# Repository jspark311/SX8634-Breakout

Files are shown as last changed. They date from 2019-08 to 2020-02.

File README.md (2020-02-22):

# SX8634-Breakout

A breakout board for Semtech's SX8634 capacitive touch sensor.

#### [Hackaday.io Page](https://hackaday.io/project/166853-sx8634-touch-sensor-breakout)

#### [Order from Tindie](https://www.tindie.com/products/17862/)

#### [Arduino driver](https://github.com/jspark311/Arduino-SX8634)

------------------------

### What is in this repository:

**./doc**:  Location for documentation

**./KiCAD**:  Hardware design files

**./lib**:  Third-party libraries

**./main**:  The optional provisioning program

**./downloadDeps.sh**   A script to download dependencies

------------------------

### Building the provisioning program

The provisioning program is intended to be run on an ESP32 devkit-C or comparable. It can be built by doing...

    ./downloadDeps.sh
    make

Then, flash it to the ESP32 board....

    make flash monitor

------------------------

Front | Back
:-------:|:------:
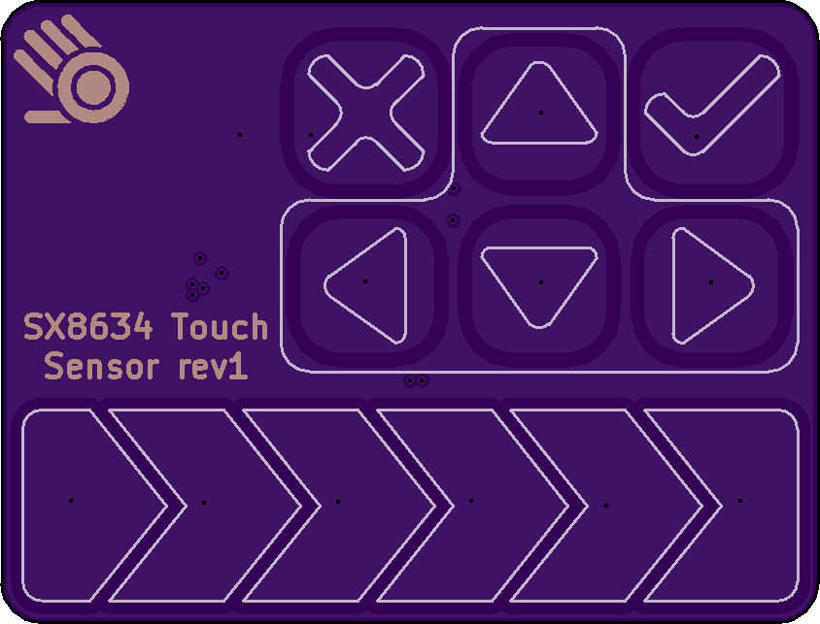
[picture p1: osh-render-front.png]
Front
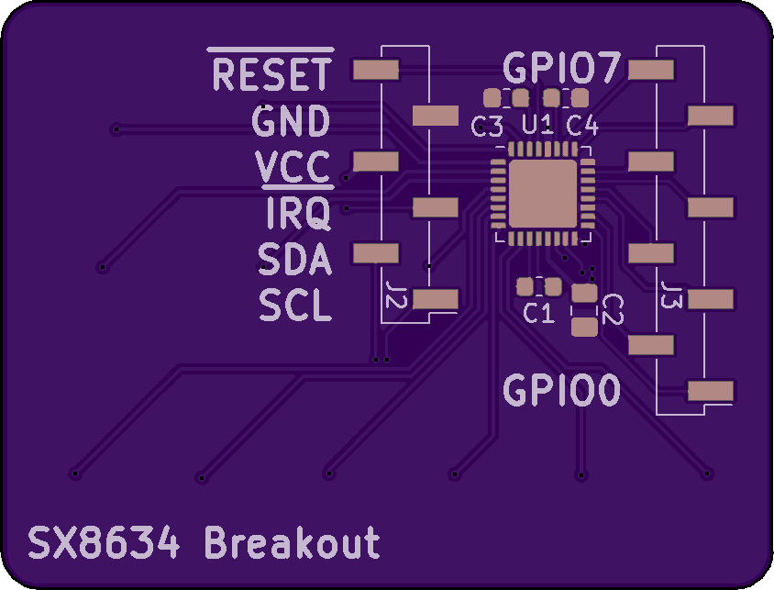
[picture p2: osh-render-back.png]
Back
  | 

[](https://oshpark.com/shared_projects/KLEZLMEO)

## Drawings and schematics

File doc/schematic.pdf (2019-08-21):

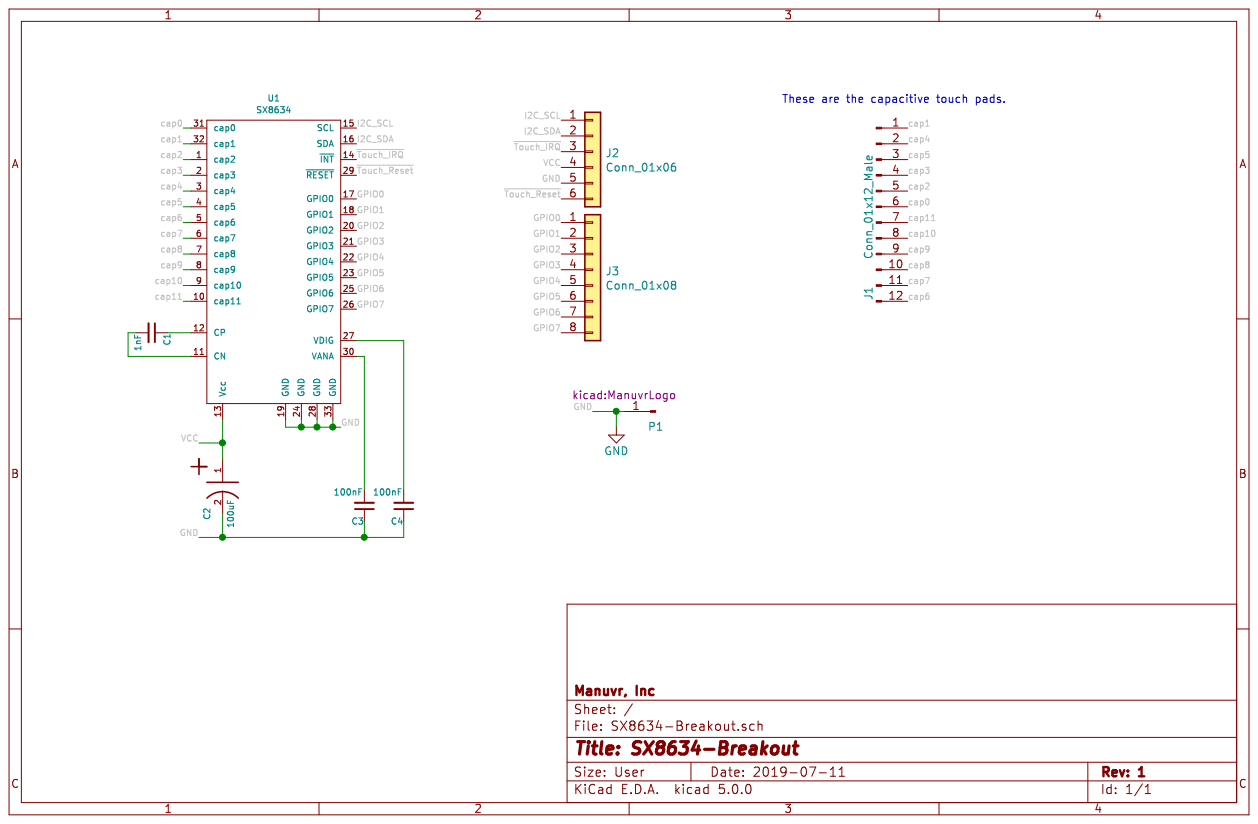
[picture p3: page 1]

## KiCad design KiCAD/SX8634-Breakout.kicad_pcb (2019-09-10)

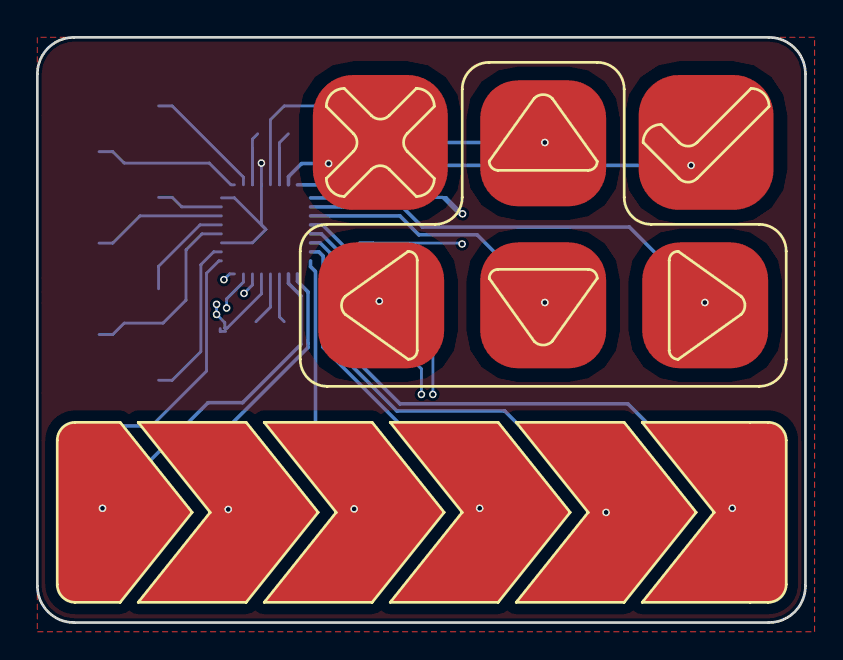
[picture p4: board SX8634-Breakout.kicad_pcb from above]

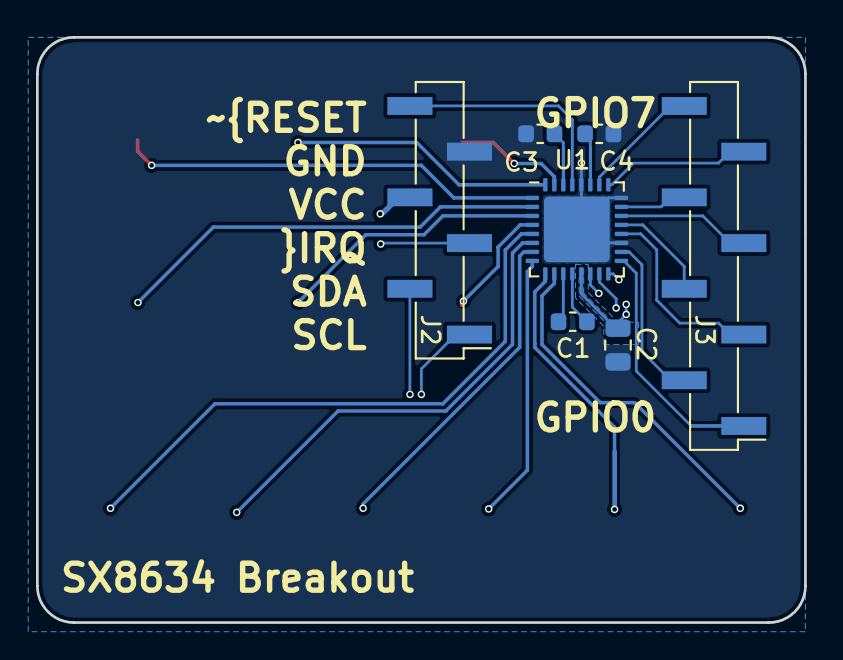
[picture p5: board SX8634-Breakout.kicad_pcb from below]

Board: 4 copper layers, 42.7 x 32.5 mm, 9 parts (7 on the bottom side), 30 nets.

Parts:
C1: 1nF; C_0603_1608Metric
C2: 100uF; C_0805_2012Metric
C3, C4: 100nF; C_0603_1608Metric
J1: Conn_01x12_Male; Cap-Touch_pattern_compact
J2: Conn_01x06; PinHeader_1x06_P2.54mm_Vertical_SMD_Pin1Left
J3: Conn_01x08; PinHeader_1x08_P2.54mm_Vertical_SMD_Pin1Left
P1: CONN_01X01; ManuvrLogo
U1: SX8634; QFN-32-1EP_5x5mm_P0.5mm_EP3.65x3.65mm

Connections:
/GPIO0: J3.1, U1.17
/GPIO1: J3.2, U1.18
/GPIO2: J3.3, U1.20
/GPIO3: J3.4, U1.21
/GPIO4: J3.5, U1.22
/GPIO5: J3.6, U1.23
/GPIO6: J3.7, U1.25
/GPIO7: J3.8, U1.26
/I2C_SCL: J2.1, U1.15
/I2C_SDA: J2.2, U1.16
/VCC: C2.1, J2.4, U1.13
/cap0: J1.6, U1.31
/cap1: J1.1, U1.32
/cap2: J1.5, U1.1
/cap3: J1.4, U1.2
/cap4: J1.2, U1.3
/cap5: J1.3, U1.4
/cap6: J1.12, U1.5
/cap7: J1.11, U1.6
/cap8: J1.10, U1.7
/cap9: J1.9, U1.8
/cap10: J1.8, U1.9
/cap11: J1.7, U1.10
/~Touch_IRQ: J2.3, U1.14
/~Touch_Reset: J2.6, U1.29
GND: C2.2, C3.1, C4.1, J2.5, U1.19, U1.24, U1.28, U1.33
unnamed: C1.1, U1.12
unnamed: C1.2, U1.11
unnamed: C3.2, U1.30
unnamed: C4.2, U1.27

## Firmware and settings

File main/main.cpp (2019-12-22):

/**
* SX8634 provisioner
*
* This is Ian's tool for provisioning and testing Manuvr's touch boards. It is
*   being provided to inform the efforts of intrepid users who want to burn a
*   customized configuration to their board's non-volatile memory (NVM).
*
* This process is only needed if...
*   1) The GPIO pins are used as inputs, and the circuit can't abide pin contention.
*   2) The default settings are in some other way inadequate and instant-on is desired.
*
* If these cases don't apply to a given application, the boards can be used as-is.
* The only thing special about this program are the build-time options...
* #define CONFIG_MANUVR_SX8634         // Needed in any application using the touch board.
* #define CONFIG_SX8634_PROVISIONING   // Only needed to provision.
*
* A finished application would use CONFIG_MANUVR_SX8634, and possibly also
*   CONFIG_SX8634_CONFIG_ON_FAITH.
*
* CONFIG_SX8634_CONFIG_ON_FAITH causes the driver to skip the step of reading
*   the configuration from the chip on every boot. During this time, the chip
*   will be unresponsive to touch, and most applications will already know what
*   the loaded configuration will be. Using this option requires the config to
*   be provided to the driver during instantiation. The program will fail at
*   runtime if this configuration is not provided.
*
* Burning the NVM requires that the part be run a little bit hotter than the
*   rest of the system (3.6v). So the hardware needs to respect that fact also.
*   Trying to burn the NVM outside of this voltage range doesn't appear to cause
*   any damage, but it won't actually burn the NVM, and the chip won't tell you
*   why it failed. So it's on the user to ensure the voltage is adequate.
* The provisioning hardware level-shifts the GPIO pins for the sake of testing
*   the boards.
*
* Pins
* -------------
* IO33   SX8634 reset pin via level-shifter
* IO35   SX8634 IRQ pin via level-shifter with 3.3v pullup
* IO32   SCL
* IO25   SDA
*
* IO23   3.6v regulator enable line
* IO13   SX8634 GPIO0 via level-shifter
* IO14   SX8634 GPIO1 via level-shifter
* IO27   SX8634 GPIO2 via level-shifter
* IO26   SX8634 GPIO3 via level-shifter
* IO18   SX8634 GPIO4 via level-shifter
* IO19   SX8634 GPIO5 via level-shifter
* IO22   SX8634 GPIO6 via level-shifter
* IO21   SX8634 GPIO7 via level-shifter
*/

#include <math.h>

#include <Platform/Platform.h>
#include <Platform/Peripherals/I2C/I2CAdapter.h>
#include <XenoSession/Console/ManuvrConsole.h>
#include <Drivers/SX8634/SX8634.h>
#include "SX8634BitDiddler.h"

#ifdef __cplusplus
extern "C" {
#endif

#include <string.h>
#include <time.h>
#include <sys/time.h>
#include "freertos/FreeRTOS.h"
#include "freertos/task.h"
#include "freertos/event_groups.h"
#include "freertos/queue.h"

#include "rom/ets_sys.h"
#include "soc/dport_reg.h"
#include "soc/io_mux_reg.h"
#include "soc/rtc_cntl_reg.h"
#include "soc/gpio_reg.h"
#include "soc/gpio_sig_map.h"
#include "rom/gpio.h"
#include "driver/gpio.h"

#include "esp_system.h"
#include "esp_event_loop.h"
#include "esp_log.h"
#include "esp_attr.h"
#include "esp_sleep.h"
#include "nvs_flash.h"

#include "esp_task_wdt.h"
#include "esp_err.h"
#include "esp_event.h"


const I2CAdapterOptions i2c_opts(
  0,   // Device number
  25,  // sda
  32,  // scl
  0,   // No pullups.
  400000
);

/*
* If we care to setup the SX8634 differently than it comes shipped, we need to
*   provide a binary blob containing the parameters we want. Since this setup
*   takes time, and has implications for circuit safety, this blob ought to be
*   provisioned into the NVM once it is finalized for a given application.
* Only non-reserved values should be placed in the blob (97 bytes). Specifying
*   reserved bytes will have undefined (possibly disasterous) results. Nor
*   should the CRC value be supplied.
* If the NVM has already been written with the desired data, or the existing
*   configuration is the desired one, then this blob, and its reference in the
*   SX8634Opts, can be omitted and class will accept the existing config.
*/
const uint8_t sx8634_conf[97] = {
  0x2b, 0x02, 0x0E, 0x05, 0x01, 0xaa, 0xa5, 0x55, 0x00, 0x00, 0x00, 0x00, 0x00, 0x00,
  0xa0, 0xa0, 0xa0, 0xa0, 0xa0, 0xa0, 0xa0, 0xa0, 0xa0, 0xa0, 0xa0, 0xa0, 0x00, 0x30,
  0x50, 0x50, 0x01, 0x0a, 0x00, 0x00, 0x00, 0x03, 0x01, 0x80, 0x50, 0x50, 0x01, 0x02,
  0x00, 0x00, 0x00, 0x00, 0x00, 0x00, 0x00, 0xcd, 0x30, 0x00, 0x00, 0x3f, 0x02,

  0x56, 0xA0, // GPIO mode
  0x00, // pwrup state
  0x00, // autolight
  0x00, // polarity
  0xff, 0xff, 0xff, 0xff, 0xff, 0xff, 0xff, 0xff, // GPIO intensity ON
  0x00, 0x00, 0x00, 0x00, 0x00, 0x00, 0x00, 0x00, // GPIO intensity OFF
  0x00, // GPIO fxn
  0x00, // Increment factor
  0x00, // Decrement factor
  0x00, 0x00, 0x00, 0x00, // Increment time
  0x44, 0x40, 0x00, 0x00, // Decrement time
  0x00, 0x00, 0x00, 0x00, // Off delay
  0x00, 0x00, // Pull resistors
  0x01, 0x70, // Interrupt
  0x00, // Debounce
  0x74
};


/*
* The given i2c address will be used in preference to the value given in the
*   config blob. So give the address that the driver should use. Not the one the
*   driver ought to provision the boards with.
*/
const SX8634Opts sx8634_opts(
  SX8634_DEFAULT_I2C_ADDR,   // i2c addr
  33,     // Reset pin
  17,     // IRQ pin
  nullptr // sx8634_conf
);


/*******************************************************************************
* Main thread                                                                  *
*******************************************************************************/

void manuvr_task(void* pvParameter) {
  Kernel* kernel = platform.kernel();
  unsigned long ms_0 = millis();
  unsigned long ms_1 = ms_0;
  bool odd_even = false;

  I2CAdapter i2c(&i2c_opts);
  kernel->subscribe(&i2c);

  SX8634BitDiddler provisioner(&i2c, 23, 13, 14, 27, 26, 18, 19, 22, 21, &sx8634_opts);
  kernel->subscribe(&provisioner);

  while (1) {
    kernel->procIdleFlags();
    ms_1 = millis();
    kernel->advanceScheduler(ms_1 - ms_0);
    ms_0 = ms_1;
    odd_even = !odd_even;
    if (0 == kernel->procIdleFlags()) {
      vTaskDelay(10 / portTICK_PERIOD_MS);
    }
  }
}



/*******************************************************************************
* Main function                                                                *
*******************************************************************************/
void app_main() {
  /*
  * The platform object is created on the stack, but takes no action upon
  *   construction. The first thing that should be done is to call the preinit
  *   function to setup the defaults of the platform.
  */
  platform.platformPreInit();
  platform.bootstrap();

  xTaskCreate(manuvr_task, "_manuvr", 32768, NULL, (tskIDLE_PRIORITY + 2), NULL);
}

#ifdef __cplusplus
}
#endif

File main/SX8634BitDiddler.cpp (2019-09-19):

#include "SX8634BitDiddler.h"
#include <Drivers/SX8634/SX8634.h>


/*******************************************************************************
*      _______.___________.    ___   .___________. __    ______     _______.
*     /       |           |   /   \  |           ||  |  /      |   /       |
*    |   (----`---|  |----`  /  ^  \ `---|  |----`|  | |  ,----'  |   (----`
*     \   \       |  |      /  /_\  \    |  |     |  | |  |        \   \
* .----)   |      |  |     /  _____  \   |  |     |  | |  `----.----)   |
* |_______/       |__|    /__/     \__\  |__|     |__|  \______|_______/
*
* Static members and initializers should be located here.
*******************************************************************************/
static SX8634BitDiddler* INSTANCE = nullptr;

static uint8_t  pf_pins[8]; // The platform GPIO pins that match the SX8634 GPIO.
static uint8_t  pin_transition_values[8];
static uint32_t pin_transition_times[8];

const MessageTypeDef message_defs_list[] = {
  {  MANUVR_MSG_SX8634_BD_SVC_REQ,    MSG_FLAG_EXPORTABLE,  "SX8634_BD_SVC_REQ",    ManuvrMsg::MSG_ARGS_NONE }  //
};


void sx_gpio_0_isr() {
  uint8_t sxpin = 0;
  pin_transition_times[sxpin]  = micros();
  pin_transition_values[sxpin] = readPin(pf_pins[sxpin]) ? 1 : 0;
}

void sx_gpio_1_isr() {
  uint8_t sxpin = 1;
  pin_transition_times[sxpin]  = micros();
  pin_transition_values[sxpin] = readPin(pf_pins[sxpin]) ? 1 : 0;
}

void sx_gpio_2_isr() {
  uint8_t sxpin = 2;
  pin_transition_times[sxpin]  = micros();
  pin_transition_values[sxpin] = readPin(pf_pins[sxpin]) ? 1 : 0;
}

void sx_gpio_3_isr() {
  uint8_t sxpin = 3;
  pin_transition_times[sxpin]  = micros();
  pin_transition_values[sxpin] = readPin(pf_pins[sxpin]) ? 1 : 0;
}

void sx_gpio_4_isr() {
  uint8_t sxpin = 4;
  pin_transition_times[sxpin]  = micros();
  pin_transition_values[sxpin] = readPin(pf_pins[sxpin]) ? 1 : 0;
}

void sx_gpio_5_isr() {
  uint8_t sxpin = 5;
  pin_transition_times[sxpin]  = micros();
  pin_transition_values[sxpin] = readPin(pf_pins[sxpin]) ? 1 : 0;
}

void sx_gpio_6_isr() {
  uint8_t sxpin = 6;
  pin_transition_times[sxpin]  = micros();
  pin_transition_values[sxpin] = readPin(pf_pins[sxpin]) ? 1 : 0;
}

void sx_gpio_7_isr() {
  uint8_t sxpin = 7;
  pin_transition_times[sxpin]  = micros();
  pin_transition_values[sxpin] = readPin(pf_pins[sxpin]) ? 1 : 0;
}




/*******************************************************************************
*   ___ _              ___      _ _              _      _
*  / __| |__ _ ______ | _ ) ___(_) |___ _ _ _ __| |__ _| |_ ___
* | (__| / _` (_-<_-< | _ \/ _ \ | / -_) '_| '_ \ / _` |  _/ -_)
*  \___|_\__,_/__/__/ |___/\___/_|_\___|_| | .__/_\__,_|\__\___|
*                                          |_|
* Constructors/destructors, class initialization functions and so-forth...
*******************************************************************************/

/*
* Constructor.
*/
SX8634BitDiddler::SX8634BitDiddler(I2CAdapter* i2c, uint8_t _pwr, uint8_t g0, uint8_t g1, uint8_t g2, uint8_t g3, uint8_t g4, uint8_t g5, uint8_t g6, uint8_t g7, const SX8634Opts* sx8634_o)
    : EventReceiver("SX8634BitDiddler"), _PWR_PIN(_pwr), touch(sx8634_o) {
  INSTANCE = this;
  pf_pins[0] = g0;
  pf_pins[1] = g1;
  pf_pins[2] = g2;
  pf_pins[3] = g3;
  pf_pins[4] = g4;
  pf_pins[5] = g5;
  pf_pins[6] = g6;
  pf_pins[7] = g7;
  _platform_gpio_make_safe();
  gpioDefine(_PWR_PIN, GPIOMode::OUTPUT);
  setPin(_PWR_PIN, true);       // Turn on power to the touch board.
  for (uint8_t i = 0; i < 8; i++) {
    pin_transition_times[i] = 0;
  }

  int mes_count = sizeof(message_defs_list) / sizeof(MessageTypeDef);
  ManuvrMsg::registerMessages(message_defs_list, mes_count);
  i2c->addSlaveDevice((I2CDevice*) &touch);
}


/*
* Destructor.
*/
SX8634BitDiddler::~SX8634BitDiddler() {
}



/*******************************************************************************
* Touch
*******************************************************************************/

int8_t SX8634BitDiddler::_platform_gpio_reconfigure() {
  local_log.concat("Putting platform GPIO into testing mode.\n");

  _gpio_safety(false);
  for (uint8_t i = 0; i < 8; i++) {
    bool using_isr = false;
    GPIOMode pptm;
    switch (touch.getGPIOMode(i)) {
      case GPIOMode::ANALOG_OUT:
      case GPIOMode::OUTPUT:
        pptm = GPIOMode::INPUT;
        using_isr = true;
        break;
      case GPIOMode::INPUT:
      case GPIOMode::INPUT_PULLUP:
      case GPIOMode::INPUT_PULLDOWN:
        pptm = GPIOMode::OUTPUT;
        break;

      default:
        pptm = GPIOMode::INPUT_PULLUP;
        using_isr = true;
        break;
    }
    local_log.concatf("SX8634 pin %u has mode: %s.  Setting platform pin %u to mode: %s\n",
      i,
      Platform::getPinModeStr(touch.getGPIOMode(i)),
      pf_pins[i],
      Platform::getPinModeStr(pptm)
    );
    if (255 != pf_pins[i]) {
      if (using_isr) {
        unsetPinIRQ(pf_pins[i]);
      }
      gpioDefine(pf_pins[i], pptm);
      if (using_isr) {
        switch (i) {
          case 0:  setPinFxn(pf_pins[i], CHANGE_PULL_UP, sx_gpio_0_isr);  break;
          case 1:  setPinFxn(pf_pins[i], CHANGE_PULL_UP, sx_gpio_1_isr);  break;
          case 2:  setPinFxn(pf_pins[i], CHANGE_PULL_UP, sx_gpio_2_isr);  break;
          case 3:  setPinFxn(pf_pins[i], CHANGE_PULL_UP, sx_gpio_3_isr);  break;
          case 4:  setPinFxn(pf_pins[i], CHANGE_PULL_UP, sx_gpio_4_isr);  break;
          case 5:  setPinFxn(pf_pins[i], CHANGE_PULL_UP, sx_gpio_5_isr);  break;
          case 6:  setPinFxn(pf_pins[i], CHANGE_PULL_UP, sx_gpio_6_isr);  break;
          case 7:  setPinFxn(pf_pins[i], CHANGE_PULL_UP, sx_gpio_7_isr);  break;
        }
      }
    }
  }
  flushLocalLog();
  return 0;
}



int8_t SX8634BitDiddler::_platform_gpio_make_safe() {
  local_log.concat("Putting platform GPIO into INPUT_PULLUP mode.\n");

  for (uint8_t i = 0; i < 8; i++) {
    if (255 != pf_pins[i]) {
      gpioDefine(pf_pins[i], GPIOMode::INPUT_PULLUP);
      unsetPinIRQ(pf_pins[i]);
    }
  }
  _gpio_safety(true);
  flushLocalLog();
  return 0;
}





/*******************************************************************************
* ######## ##     ## ######## ##    ## ########  ######
* ##       ##     ## ##       ###   ##    ##    ##    ##
* ##       ##     ## ##       ####  ##    ##    ##
* ######   ##     ## ######   ## ## ##    ##     ######
* ##        ##   ##  ##       ##  ####    ##          ##
* ##         ## ##   ##       ##   ###    ##    ##    ##
* ########    ###    ######## ##    ##    ##     ######
*
* These are overrides from EventReceiver interface...
*******************************************************************************/
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

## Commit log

2019-08-09 Adding KiCAD files.
    [SX8634-Breakout-B.Cu.gbr, SX8634-Breakout-B.Mask.gbr, SX8634-Breakout-B.Paste.gbr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]
2019-08-09 Removing fab files.
    [SX8634-Breakout-B.Cu.gbr, SX8634-Breakout-B.Mask.gbr, SX8634-Breakout-B.Paste.gbr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]
2019-08-09 Adding files and finishing up.
    [SX8634-Breakout.sch]
2019-08-19 Preparing for Arduino driver. Adding some reliability and provisioning features.
2019-08-21 Changing design for the sake of a cap array going obsolete.
    [SX8634-Breakout.kicad_pcb, SX8634-Breakout.sch]
2019-08-21 Fixing a naming mistake. Updating README.
    [SX8634-Breakout.kicad_pcb, SX8634-Breakout.sch]
2019-08-21 Adding arduino boilerplate and an unported driver.
2019-09-10 Removed obsoleted cap array.
    [SX8634-Breakout.kicad_pcb]
2019-09-14 Adding Arduino driver and example. Not working yet.
2019-09-29 Library compiles, but Fails to read SPM. Sync Arduino i2c API is simpler. Driver will lose more complexity.
2019-10-08 Updating board images and README. Arduino driver is working.
2019-12-22 Changing demo config. Fixing name.
    [main.cpp]
2020-02-22 Arduino driver is now in the Library manager.
